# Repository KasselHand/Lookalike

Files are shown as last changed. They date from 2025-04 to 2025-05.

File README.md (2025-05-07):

    Kassel Hand Project Lookalike Printable Model README

    This file repository contains the files for the Lookalike model of the Kassel Hand. 
    Its interior components appear and move like the original artifact, but these components 
    are fragile because of their construction. If you have questions about this repository's 
    purpose or are unsure of how to start the printing process, head back to this model's webpage 
    and check out the section titled, "New to Printing?" Happy printing!

    1.) File Naming Convention--"L-##-[Name of Part]-#X"
        
        a.) Frist Section, L is a letter, either "M" for Mechanism or "S" for Shell.
                i.) Shell was printed out of gray and is a structural part.
               ii.) Mechanism is any movable part that is integral to the actuation.
        b.) Next section is two numbers to identify the part. The presence of the letter L means it 
            is a part unique to the Lookalike. "Alt" means this is an alternative part with the 
            ability to use either option. M11L Alt is a ratchet release that looks closer to the 
            original but is less functional.
        c.) The "Name of Part" is the colloquial term for the part in question. i.e. it's
            it's easier to identify if you need a new ring finger than a 
            replacement "M-03."
        d.) "#X" is how many copies are needed.
    
    2.) Print Settings

        a.) General Print Settings
                i.) An Anycubic Kobra 3 with the Anycubic Slicer.
               ii.) 2 Vertical Shells, 4 Horizontal Shells with a minimum thickness of 0.6mm
              iii.) 15% infill density, grid pattern
               iv.) 0.16mm layer height
                v.) Organic supports with a 0.28mm Z contact distance and 2.5mm spacing
               vi.) Top and bottom interface layers should be 3 layers thick
              vii.) Print the paddle (M-11) oriented where the flat of the paddle is normal 
                    to the plate and the rod is prarllel. While this may seem like the 
                    worst oritnetation to print, the goal is to have the layer lines run 
                    along the rod and for the presence of unbroken layers circumnavigating 
                    the entire rod and paddle. This is for maximum strength.
                        1.) If you are using this as a display model, then you can print it 
                            with the thin rod on the plate with the paddle pointed up, 
                            like a letter "L" rotated backwards 90 degrees.
               ix.) Print both shells, files that begin with "S##" vertically. That is, the 
                    region where the fingers will eventually be installed should be pointed 
                    upwards and the wrist end of the gauntlet should be on the plate.
                x.) Print the rest of the mechanism parts, those with file names starting 
                    with "M##" with their flattest end on the plate. This includes all 
                    fingers: M-07, M-08, M-09, and M-10.
               xi.) M-13 and M-14, the axles, can be printed horizontally. The rod rests 
                    lengthwise along the plate.
              xii.) M-15 is an exception to direction viii--for best results, we have found 
                    printing with the loop parallel to the plate is best.
             xiii.) M-16 should be printed with the loop flat on the plate as you would 
                    expect a ring to sit atop a table.

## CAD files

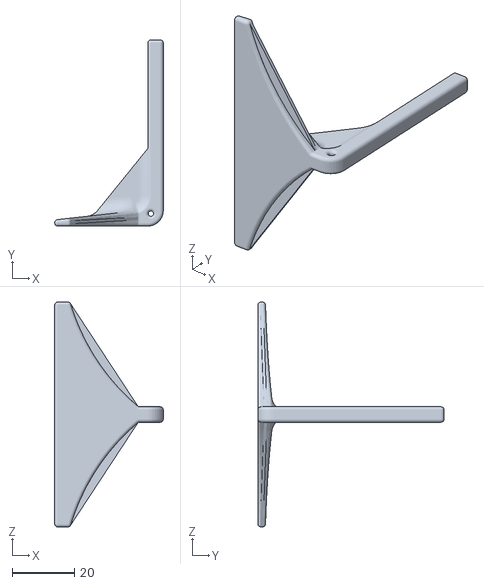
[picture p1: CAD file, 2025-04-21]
M-11L-Ratchet Release Paddle-1X.STL
35.0 x 60.0 x 72.5

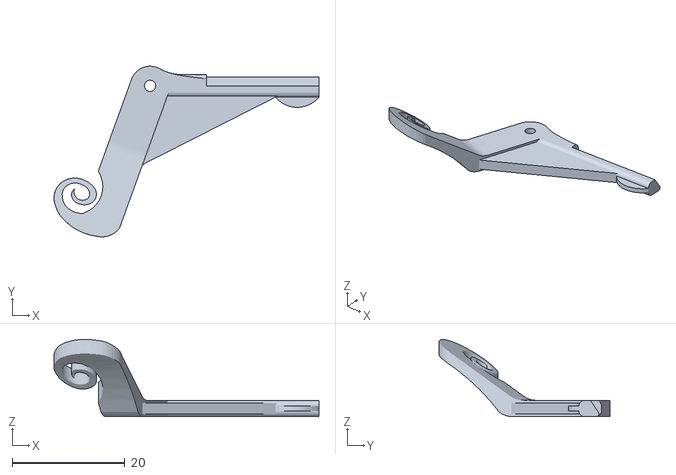
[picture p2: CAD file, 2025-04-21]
M-12L-Thumb Pawl Lever Lookalike-1X.STL
47.1 x 30.3 x 13.7

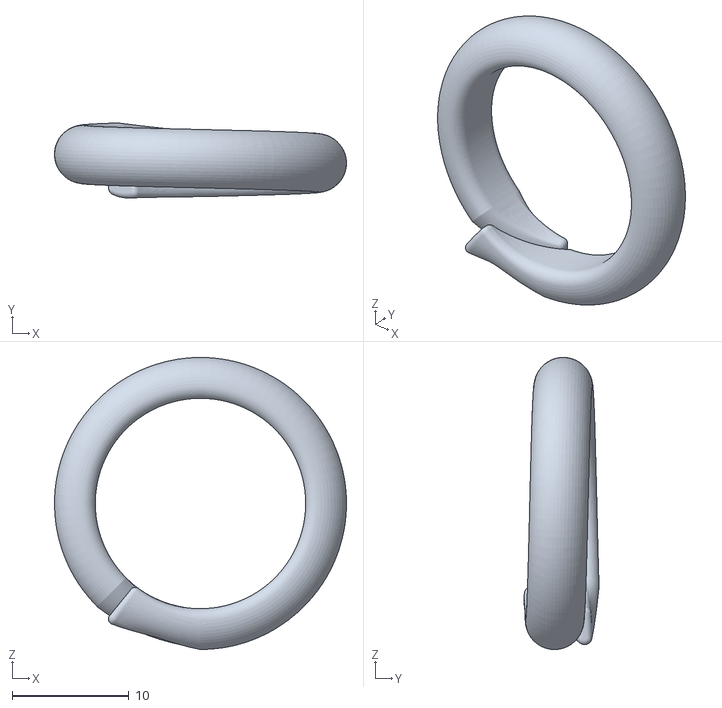
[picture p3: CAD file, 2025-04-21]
M-16-Wrist Ring-1X.STL
25.0 x 6.43 x 25.0

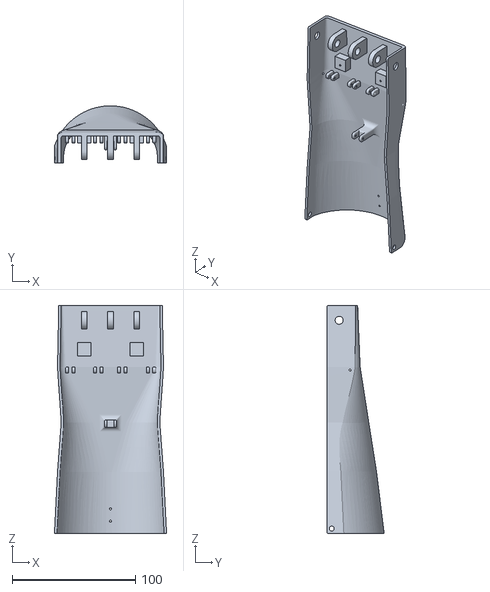
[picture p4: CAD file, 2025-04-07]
S-02-Facsimile Top-1x.STL
90.9 x 46.5 x 185.0

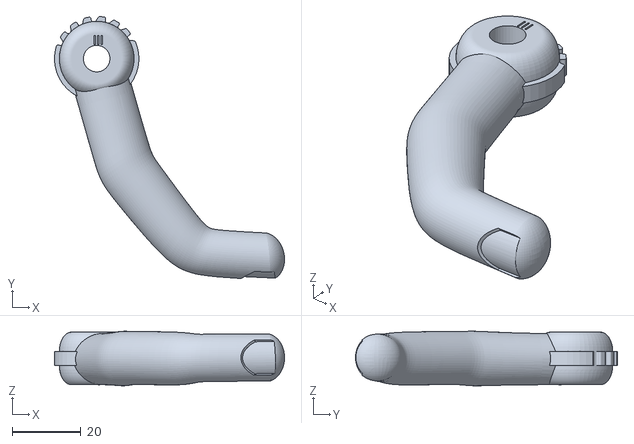
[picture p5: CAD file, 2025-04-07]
M-03-Ring Finger V4-1X.STL
66.7 x 75.9 x 15.8

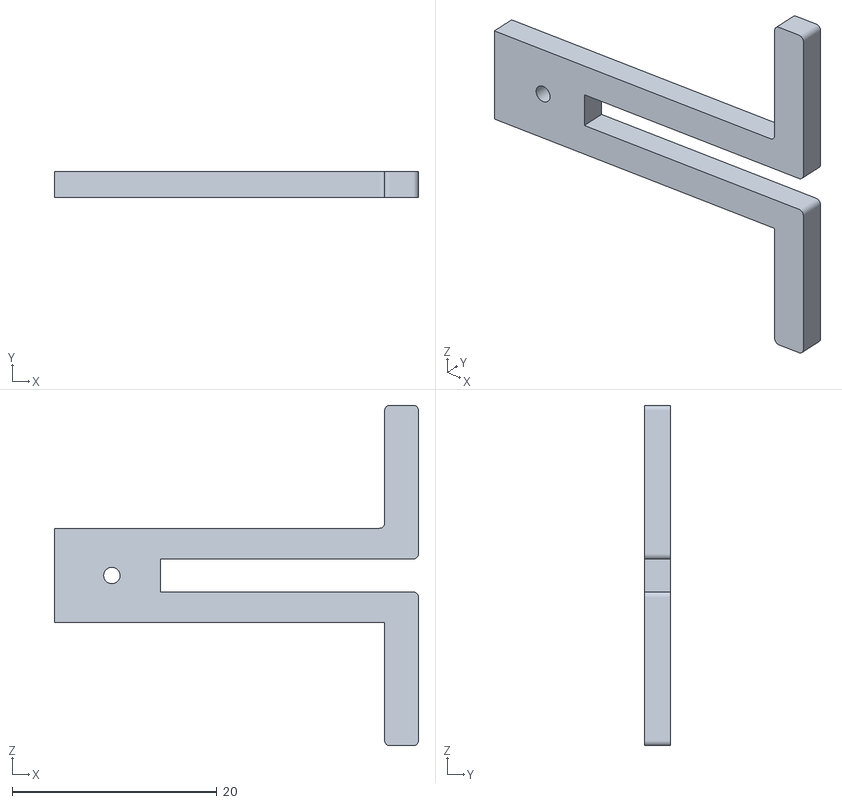
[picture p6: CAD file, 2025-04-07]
M-07-Finger Spring-2X.STL
35.5 x 2.54 x 33.2

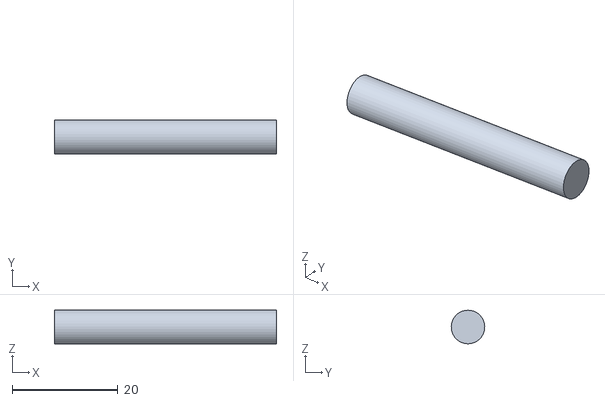
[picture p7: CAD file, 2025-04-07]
M-14-Thumb Axle-1X.STL
42.0 x 6.34 x 6.35

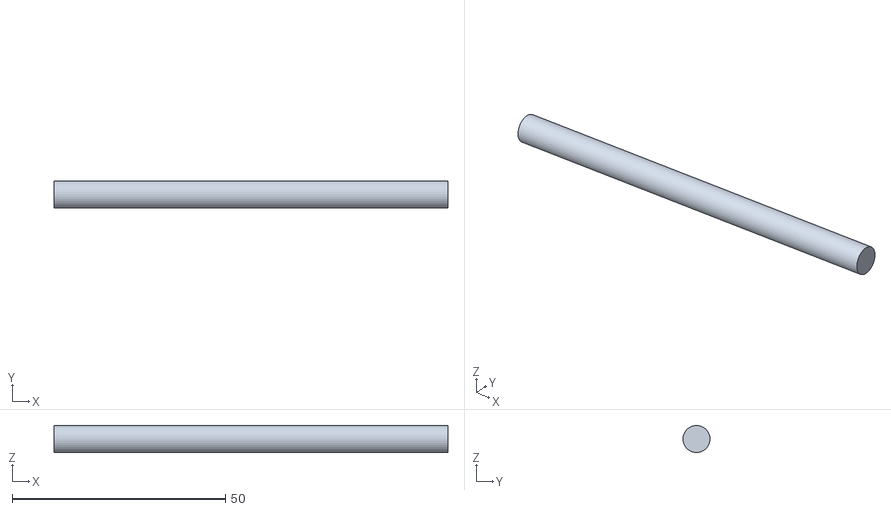
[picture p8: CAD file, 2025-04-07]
M-13-Finger Axle-1X.STL
92.3 x 6.34 x 6.35

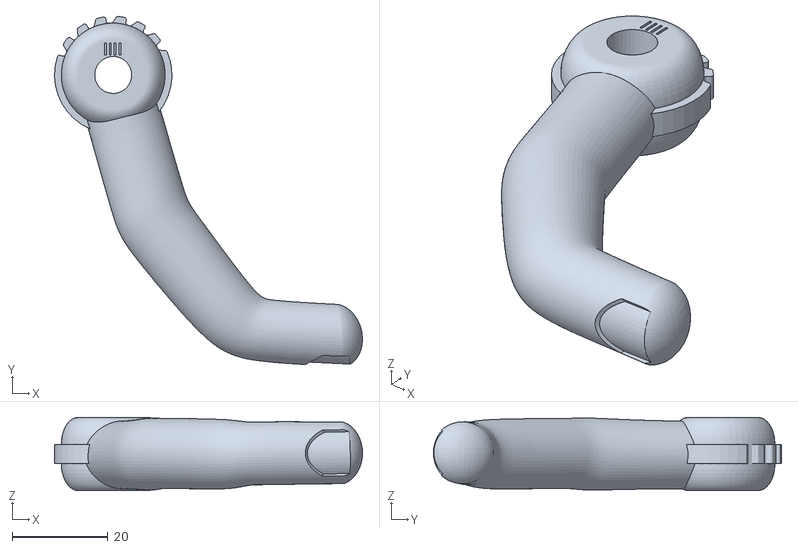
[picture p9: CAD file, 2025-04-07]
M-04-Little Finger V4-1X.STL
64.2 x 72.6 x 15.2

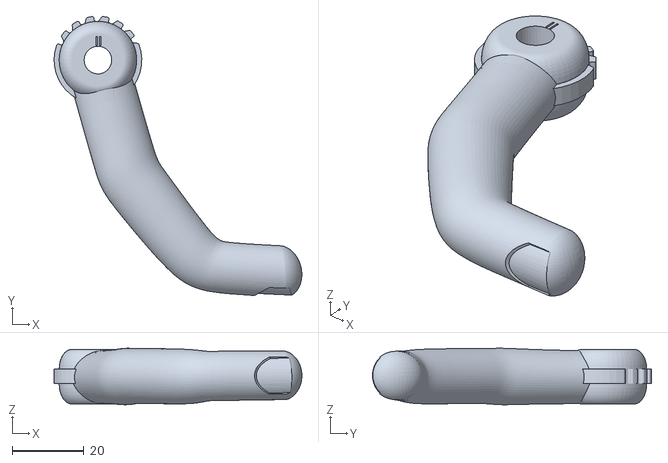
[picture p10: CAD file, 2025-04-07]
M-02-Middle Finger V4-1X.STL
69.2 x 77.9 x 15.8

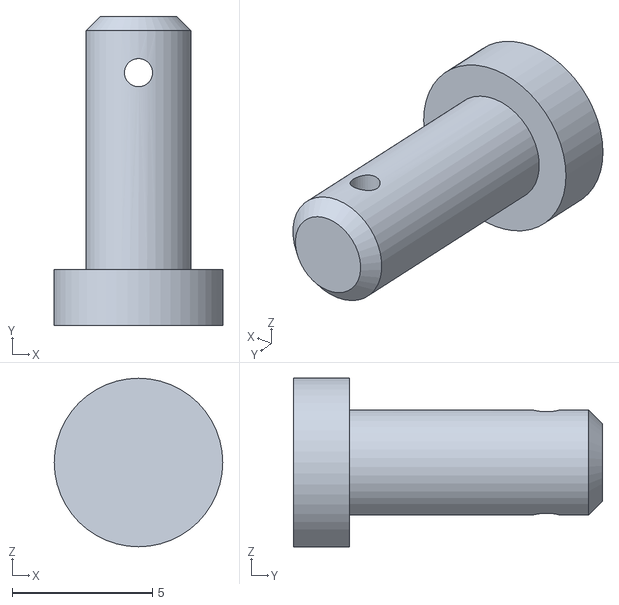
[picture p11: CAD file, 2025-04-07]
M-10-Retaining Pins-2X.STL
6.00 x 11.0 x 6.00

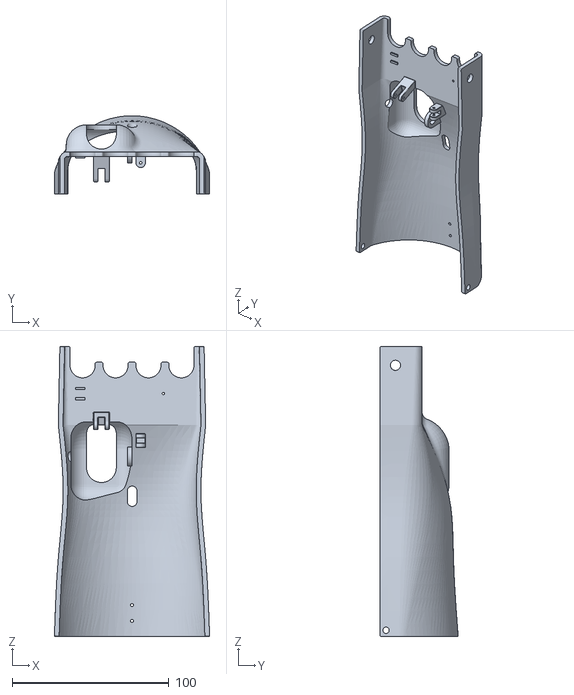
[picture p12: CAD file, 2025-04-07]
S-01-Gauntlet Bottom V4-1X.STL
99.0 x 50.0 x 185.0

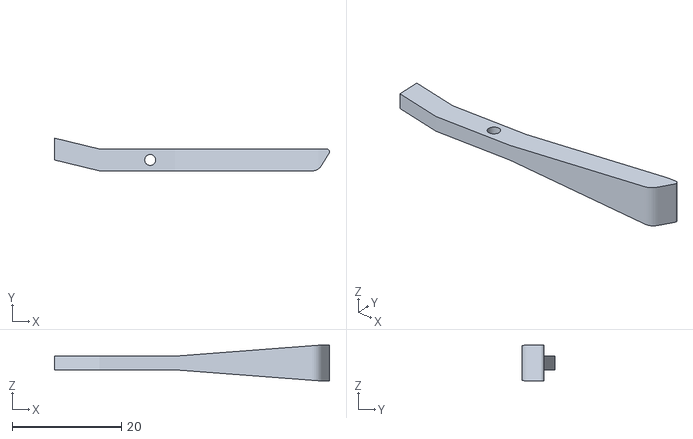
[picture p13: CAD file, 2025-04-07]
M-06-Finger Pawl-4X.STL
50.3 x 6.00 x 6.50

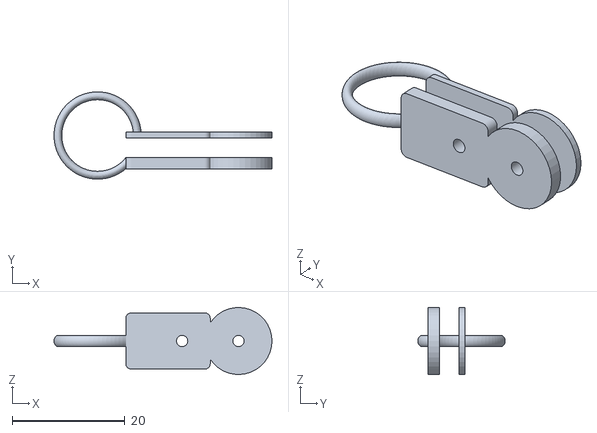
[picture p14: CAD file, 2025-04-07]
M-15-Ring Attachment-1X.STL
38.7 x 15.5 x 11.9

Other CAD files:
M-09-Thumb Pawl Spring-1X.STL
M-01-Index Finger V4-1X.STL
M-11L Alt-Ratchet Release Paddle-1X.STL
M-05-Thumb V4-1X.STL
M-08-Thumb Spring-1X.STL
